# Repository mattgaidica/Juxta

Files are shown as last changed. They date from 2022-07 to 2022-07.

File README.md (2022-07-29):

# Juxta
 
__TI CCS Dev__

> Use LP_CC1352P7_4 projects for your CC2652P7 device.  This is also covered in the Running Software Examples on CC2652P module of the BLE5-Stack Migration Guide.  You still need an antenna switch to determine whether to use the normal or high-PA output path, although if using a custom design with one determined path then you can choose "Use Custom Board" and remove the CONFIG_RF_* pin assignments.

* In CCS > *.syscfg click the Board icon, select "Use custom board"
* Make a new target file for CC2652P7 and right-click it active

${COM_TI_SIMPLELINK_CC13XX_CC26XX_SDK_INSTALL_DIR_REPOS}

__Base SysConfig (no RF)__

		/**
	 * These arguments were used when this file was generated. They will be automatically applied on subsequent loads
	 * via the GUI or CLI. Run CLI with '--help' for additional information on how to override these arguments.
	 * @cliArgs --device "CC1352P7RGZ" --package "RGZ" --part "Default" --rtos "tirtos7" --product "simplelink_cc13xx_cc26xx_sdk@6.10.00.29"
	 * @versions {"tool":"1.12.0+2406"}
	 */
	
	/**
	 * Import the modules used in this configuration.
	 */
	const rfdesign    = scripting.addModule("/ti/devices/radioconfig/rfdesign");
	const ADC         = scripting.addModule("/ti/drivers/ADC", {}, false);
	const ADC1        = ADC.addInstance();
	const GPIO        = scripting.addModule("/ti/drivers/GPIO");
	const GPIO2       = GPIO.addInstance();
	const GPIO3       = GPIO.addInstance();
	const GPIO4       = GPIO.addInstance();
	const GPIO5       = GPIO.addInstance();
	const GPIO6       = GPIO.addInstance();
	const GPIO7       = GPIO.addInstance();
	const GPIO8       = GPIO.addInstance();
	const Power       = scripting.addModule("/ti/drivers/Power");
	const SPI         = scripting.addModule("/ti/drivers/SPI", {}, false);
	const SPI1        = SPI.addInstance();
	const Settings    = scripting.addModule("/ti/posix/tirtos/Settings");
	const BIOS        = scripting.addModule("/ti/sysbios/BIOS");
	const Event       = scripting.addModule("/ti/sysbios/knl/Event");
	const Idle        = scripting.addModule("/ti/sysbios/knl/Idle", {}, false);
	const Idle2       = Idle.addInstance();
	const Mailbox     = scripting.addModule("/ti/sysbios/knl/Mailbox");
	const Error       = scripting.addModule("/ti/sysbios/runtime/Error");
	const SysCallback = scripting.addModule("/ti/sysbios/runtime/SysCallback");
	const Timestamp   = scripting.addModule("/ti/sysbios/runtime/Timestamp");
	
	/**
	 * Write custom configuration values to the imported modules.
	 */
	rfdesign.fbSub1g = "none";
	rfdesign.fe24g   = "ID";
	rfdesign.pa20    = "none";
	
	ADC1.$name              = "VBATT";
	ADC1.adc.adcPin.$assign = "DIO_27";
	
	GPIO2.$name           = "LED_1";
	GPIO2.mode            = "Output";
	GPIO2.outputStrength  = "Low";
	GPIO2.gpioPin.$assign = "DIO_6";
	
	GPIO3.$name              = "AXY_CS";
	GPIO3.mode               = "Output";
	GPIO3.initialOutputState = "High";
	GPIO3.gpioPin.$assign    = "DIO_16";
	
	GPIO4.$name           = "AXY_INT";
	GPIO4.pull            = "Pull Up";
	GPIO4.gpioPin.$assign = "DIO_17";
	
	GPIO5.$name           = "DEBUG";
	GPIO5.gpioPin.$assign = "DIO_22";
	
	GPIO6.$name           = "Rx";
	GPIO6.gpioPin.$assign = "DIO_24";
	
	GPIO7.$name           = "Tx";
	GPIO7.mode            = "Output";
	GPIO7.gpioPin.$assign = "DIO_25";
	
	GPIO8.$name           = "LED_0";
	GPIO8.mode            = "Output";
	GPIO8.outputStrength  = "Low";
	GPIO8.gpioPin.$assign = "DIO_26";
	
	const CCFG              = scripting.addModule("/ti/devices/CCFG", {}, false);
	CCFG.ccfgTemplate.$name = "ti_devices_CCFG_CCFGCC26XXTemplate0";
	
	SPI1.$name               = "CONFIG_SPI";
	SPI1.spi.sclkPin.$assign = "DIO_19";
	SPI1.spi.misoPin.$assign = "DIO_20";
	SPI1.spi.mosiPin.$assign = "DIO_21";
	
	BIOS.assertsEnabled = false;
	BIOS.heapBaseAddr   = "__primary_heap_start__";
	BIOS.heapEndAddr    = "__primary_heap_end__";
	
	const Hwi           = scripting.addModule("/ti/sysbios/family/arm/m3/Hwi", {}, false);
	Hwi.enableException = false;
	
	const Clock      = scripting.addModule("/ti/sysbios/knl/Clock", {}, false);
	Clock.tickPeriod = 10;
	
	const Timer       = scripting.addModule("/ti/sysbios/family/arm/cc26xx/Timer", {}, false);
	Timer.rtc.$assign = "RTC0";
	
	Idle2.$name   = "powerIdle";
	Idle2.idleFxn = "Power_idleFunc";
	
	const Semaphore            = scripting.addModule("/ti/sysbios/knl/Semaphore", {}, false);
	Semaphore.supportsPriority = false;
	
	const Swi         = scripting.addModule("/ti/sysbios/knl/Swi", {}, false);
	Swi.numPriorities = 6;
	
	const Task             = scripting.addModule("/ti/sysbios/knl/Task", {}, false);
	Task.defaultStackSize  = 512;
	Task.idleTaskStackSize = 512;
	Task.numPriorities     = 6;
	
	Error.policy       = "Error_SPIN";
	Error.printDetails = false;
	
	const System           = scripting.addModule("/ti/sysbios/runtime/System", {}, false);
	System.abortFxn        = "System_abortSpin";
	System.exitFxn         = "System_exitSpin";
	System.extendedFormats = "%f";
	System.supportModule   = "SysCallback";
	
	/**
	 * Pinmux solution for unlocked pins/peripherals. This ensures that minor changes to the automatic solver in a future
	 * version of the tool will not impact the pinmux you originally saw.  These lines can be completely deleted in order to
	 * re-solve from scratch.
	 */
	ADC1.adc.$suggestSolution              = "ADC0";
	SPI1.spi.$suggestSolution              = "SSI0";
	SPI1.spi.dmaRxChannel.$suggestSolution = "DMA_CH3";
	SPI1.spi.dmaTxChannel.$suggestSolution = "DMA_CH4";

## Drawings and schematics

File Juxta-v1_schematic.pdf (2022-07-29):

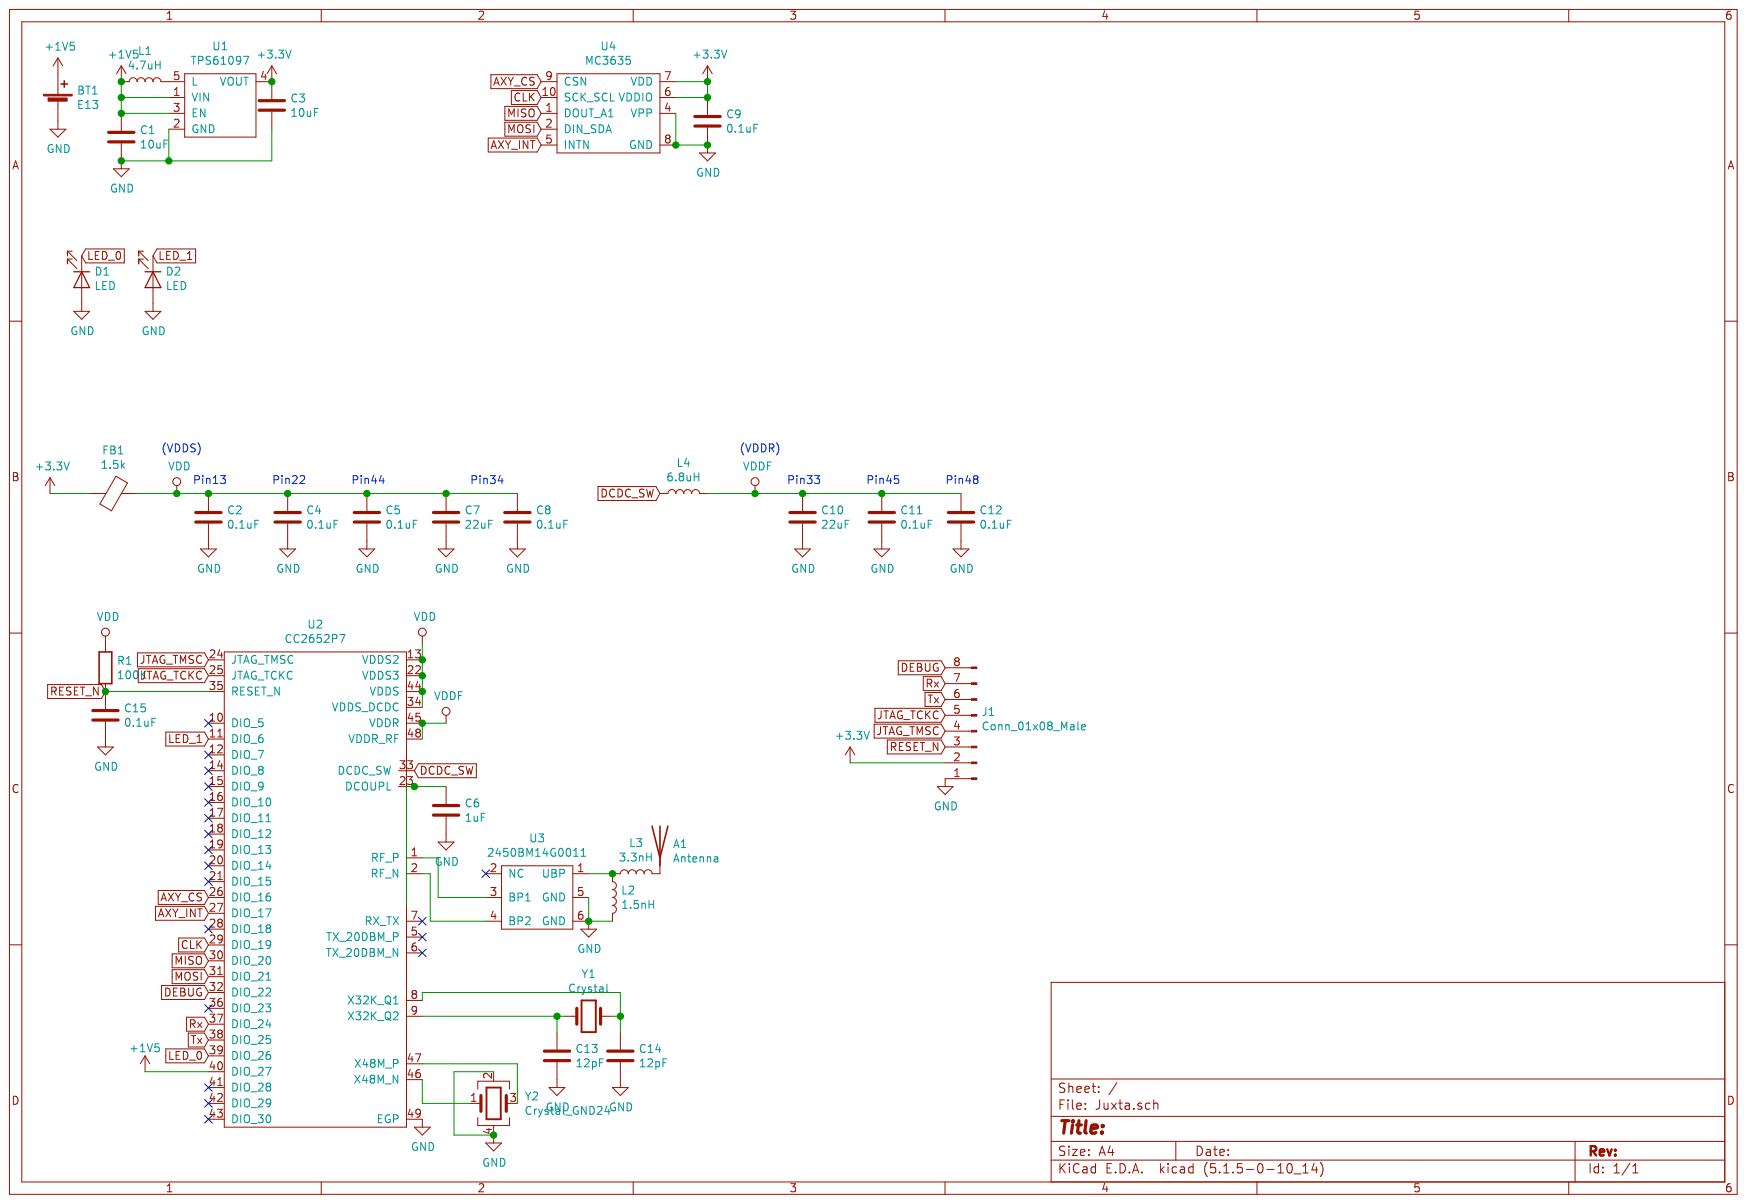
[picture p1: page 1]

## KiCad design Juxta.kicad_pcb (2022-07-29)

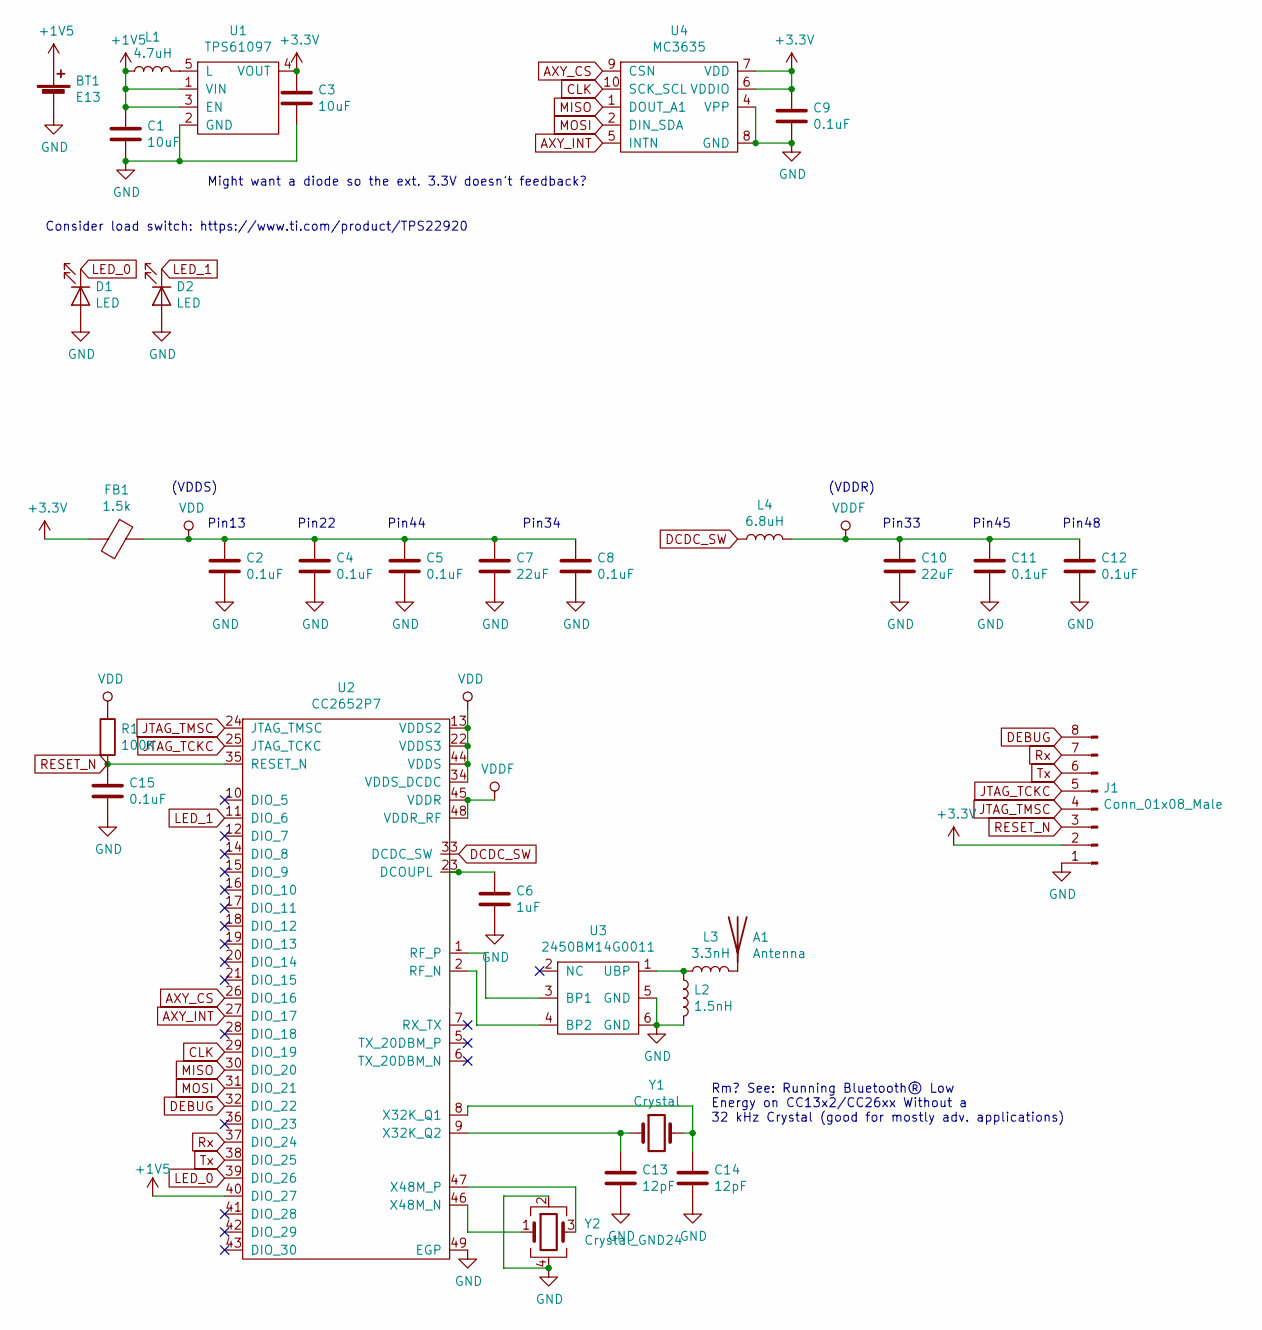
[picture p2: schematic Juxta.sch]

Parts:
A1: Antenna; 2450AT18B100; DigiKey 712-1006-1-ND
BT1: E13; 2988_7.9mmBatteryContact; DigiKey 36-2988CT-ND
C1, C3: 10uF; C_0402_1005Metric; DigiKey 13-CC0402MPX5R4BB106CT-ND
C2, C4, C5, C8, C9, C11, C12, C15: 0.1uF; C_0402_1005Metric; DigiKey 478-1126-1-ND
C6: 1uF; C_0402_1005Metric; DigiKey 478-4596-1-ND
C7, C10: 22uF; C_0402_1005Metric; DigiKey 478-04024D226MAT2ACT-ND
C13, C14: 12pF; C_0402_1005Metric; DigiKey 490-5924-2-ND
D1, D2: LED; LED_0402_1005Metric; DigiKey 1830-1056-1-ND
FB1: 1.5k; L_0402_1005Metric; DigiKey 445-2158-1-ND
J1: Conn_01x08_Male; Molex_SlimStack_502430-0820_2x04_P0.40mm_Vertical; Mouser 538-50243-00822
L1: 4.7uH; L_0603_1608Metric; DigiKey 445-6390-1-ND
L2: 1.5nH; L_0402_1005Metric; DigiKey 334-1083-1-ND
L3: 3.3nH; L_0402_1005Metric; DigiKey 490-6561-1-ND
L4: 6.8uH; L_0603_1608Metric; DigiKey 445-MLZ1608M6R8WT000CT-ND
R1: 100K; R_0402_1005Metric; DigiKey RMCF0402FT100KCT-ND
U1: TPS61097; SOT-23-5
U2: CC2652P7; QFN-48-1EP_7x7mm_P0.5mm_EP5.15x5.15mm
U3: 2450BM14G0011; DigiKey 712-1620-1-ND
U4: MC3635; LGA-10_1.6x1.6; DigiKey 2548-MC3635CT-ND
Y1: Crystal; Crystal_SMD_2012-2Pin_2.0x1.2mm; DigiKey SER4081TR-ND
Y2: Crystal_GND24; Crystal_SMD_2016-4Pin_2.0x1.6mm; DigiKey 535-13930-1-ND

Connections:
+1V5: BT1.1 (+), C1.1, L1.1, U1.1 (VIN), U1.3 (EN), U2.40 (DIO_27)
+3V3: C3.1, C9.1, FB1.2, J1.2, U1.4 (VOUT), U4.6 (VDDIO), U4.7 (VDD)
AXY_CS: U2.26 (DIO_16), U4.9 (CSN)
AXY_INT: U2.27 (DIO_17), U4.5 (INTN)
CLK: U2.29 (DIO_19), U4.10 (SCK_SCL)
DCDC_SW: L4.1, U2.33 (DCDC_SW)
DEBUG: J1.8, U2.32 (DIO_22)
GND: BT1.2 (-), C1.2, C2.2, C3.2, C4.2, C5.2, C6.2, C7.2, C8.2, C9.2, C10.2, C11.2, C12.2, C13.2, C14.2, C15.2, D1.2 (A), D2.2 (A), J1.1, L2.2, U1.2 (GND), U2.49 (EGP), U3.5 (GND), U3.6 (GND), U4.4 (VPP), U4.8 (GND), Y2.2, Y2.4
JTAG_TCKC: J1.5, U2.25 (JTAG_TCKC)
JTAG_TMSC: J1.4, U2.24 (JTAG_TMSC)
LED_0: D1.1 (K), U2.39 (DIO_26)
LED_1: D2.1 (K), U2.11 (DIO_6)
MISO: U2.30 (DIO_20), U4.1 (DOUT_A1)
MOSI: U2.31 (DIO_21), U4.2 (DIN_SDA)
unnamed: A1.1, L3.2
unnamed: C6.1, U2.23 (DCOUPL)
unnamed: C13.1, U2.9 (X32K_Q2), Y1.1
unnamed: C14.1, U2.8 (X32K_Q1), Y1.2
unnamed: L1.2, U1.5 (L)
unnamed: L2.1, L3.1, U3.1 (UBP)
unnamed: U2.1 (RF_P), U3.3 (BP1)
unnamed: U2.2 (RF_N), U3.4 (BP2)
unnamed: U2.46 (X48M_N), Y2.1
unnamed: U2.47 (X48M_P), Y2.3
RESET_N: C15.1, J1.3, R1.2, U2.35 (RESET_N)
Rx: J1.7, U2.37 (DIO_24)
Tx: J1.6, U2.38 (DIO_25)
VDD: C2.1, C4.1, C5.1, C7.1, C8.1, FB1.1, R1.1, U2.13 (VDDS2), U2.22 (VDDS3), U2.34 (VDDS_DCDC), U2.44 (VDDS)
VDDF: C10.1, C11.1, C12.1, L4.2, U2.45 (VDDR), U2.48 (VDDR_RF)

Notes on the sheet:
(VDDS)
(VDDR)
Pin33
Pin45
Pin48
Pin34
Pin44
Pin22
Pin13
Might want a diode so the ext. 3.3V doesn’t feedback?
Rm? See: Running Bluetooth® Low Energy on CC13x2/CC26xx Without a 32 kHz Crystal (good for mostly adv. applications)
Consider load switch: https://www.ti.com/product/TPS22920

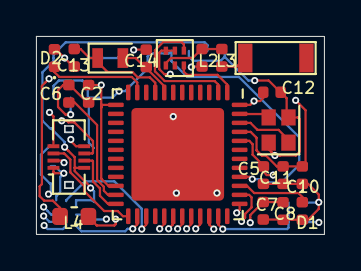
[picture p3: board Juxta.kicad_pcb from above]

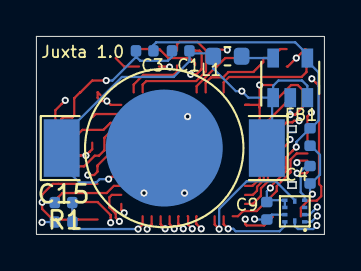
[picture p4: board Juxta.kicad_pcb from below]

Board: 4 copper layers, 16.0 x 11.0 mm, 32 parts (11 on the bottom side), 29 nets.
